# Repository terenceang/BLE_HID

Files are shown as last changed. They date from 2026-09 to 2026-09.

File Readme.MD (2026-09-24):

# SNES_BLE_HID - SNES controller to Bluetooth adapter (DA14585)

Plug an original SNES controller into this adapter and it becomes a wireless **Bluetooth LE
gamepad** - a standard HID-over-GATT device (HOGPD) that pairs with Windows, Android, iOS and
Linux with no drivers. The controller itself is untouched.

The adapter is built almost entirely from reused parts: the Bluetooth board is salvaged from an
e-paper **electronic shelf label (ESL)** (Renesas DA14585 + SPI flash; the same board as the
HMCLOCK project), powered by a reclaimed Li-ion cell with a TP4056-style USB charger and a
DC-DC converter, in a 3D-printed case. Repository: https://github.com/terenceang/SNES_BLE_HID

Firmware features: 12-button gamepad, battery level, deep sleep after 3 idle minutes (B wakes
it), and **signed over-the-air updates** - plus a PC updater and a browser tester (`tools/`).

## Hardware

| Prototype | In the case |
|---|---|
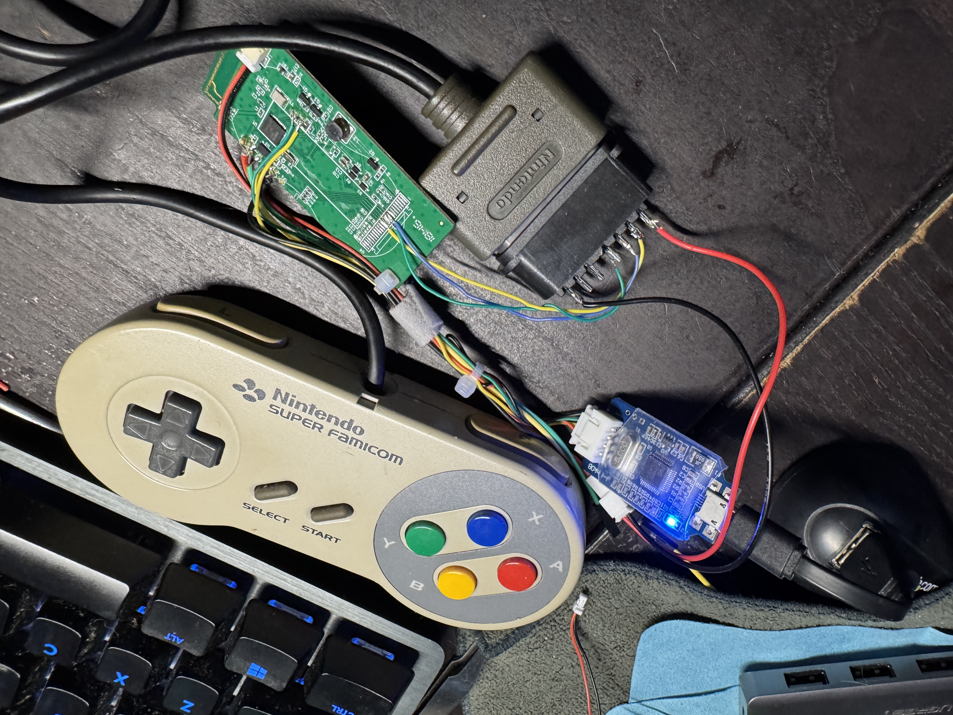
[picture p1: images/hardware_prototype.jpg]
Prototype: ESL board wired to a SNES socket, charger module and a Super Famicom pad
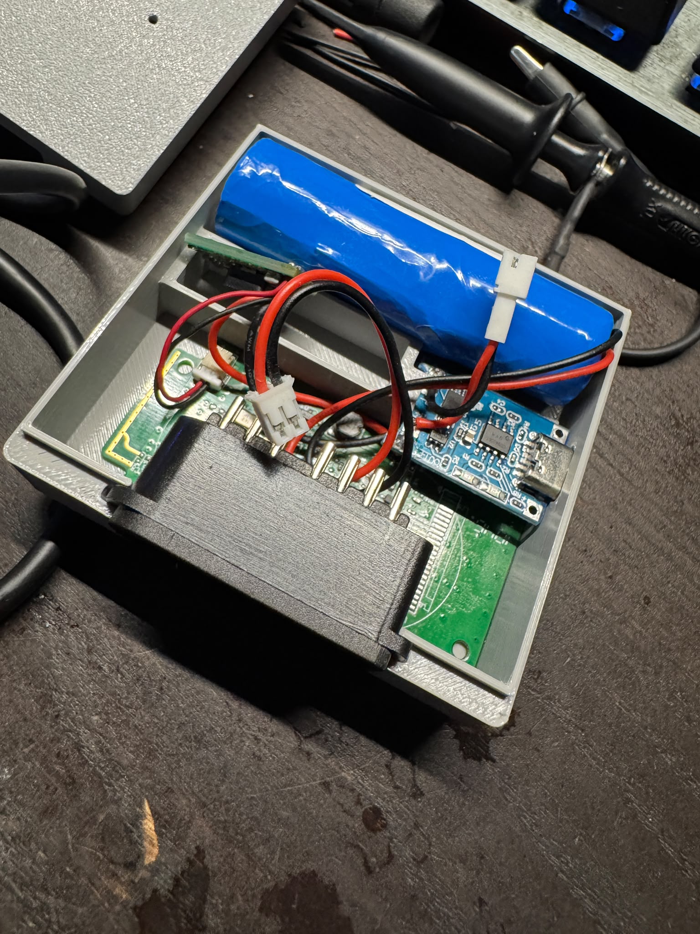
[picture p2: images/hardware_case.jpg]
Assembled: 18650 cell, USB-C charger/DC-DC module and the SNES socket on the ESL board in a 3D-printed case
|  |  |

- **Bluetooth board**: ESL board (DA14585, SPI flash, 32 kHz crystal). Its GPIOs were traced
  one by one; only three pads are needed - see [GPIO map](#gpio-map-da14585-qfn40).
- **SNES socket** wired to pads E09 (LATCH), E10 (DATA), E12 (CLOCK) plus supply and GND
  (see [Running](#running) for the pinout).
- **Power**: Li-ion cell (18650 in the case) -> USB charger module (TP4056-style, USB-C) ->
  DC-DC converter -> the board. The firmware's battery % reads the chip's supply after the
  converter, scaled 2.2 V = 0 % .. 2.8 V = 100 % (see [Battery level](#battery-level)).
- **Case**: 3D printed - see [3D-printed case](#3d-printed-case).
- **Programming**: J-Link on the test points (SWD) for the first install; after that, updates
  go over the air - see [Programming](#programming-swd).

### 3D-printed case

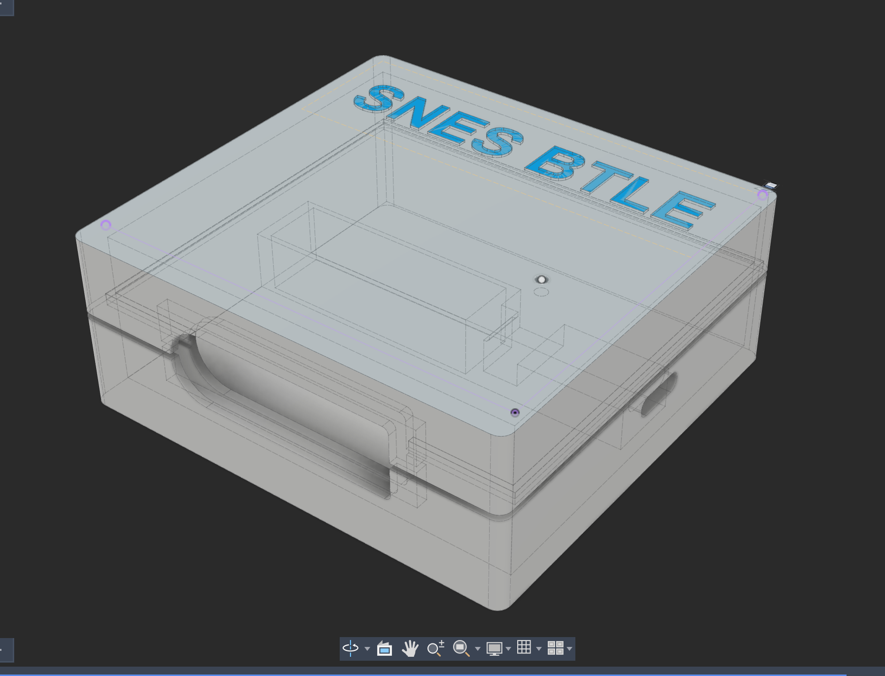
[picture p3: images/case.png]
Case model: base with SNES socket opening and USB slot, lid embossed "SNES BTLE"


CAD model: [`3D/SNES BLE.step`](3D/SNES%20BLE.step) (STEP AP214, exported from Autodesk
Fusion; opens in any CAD tool - export the bodies to STL/3MF for your slicer).

- Two parts: a **base** that holds the ESL board, the charger/DC-DC module and the cell (see
  the photo above), and a **lid** with "SNES BTLE" embossed on top.
- Front opening for the **SNES controller socket**; side slot for the **USB-C** charging port.
- Check the cell and socket fit against your own parts before printing - 18650 cells and SNES
  sockets vary slightly.

### Programming (SWD)

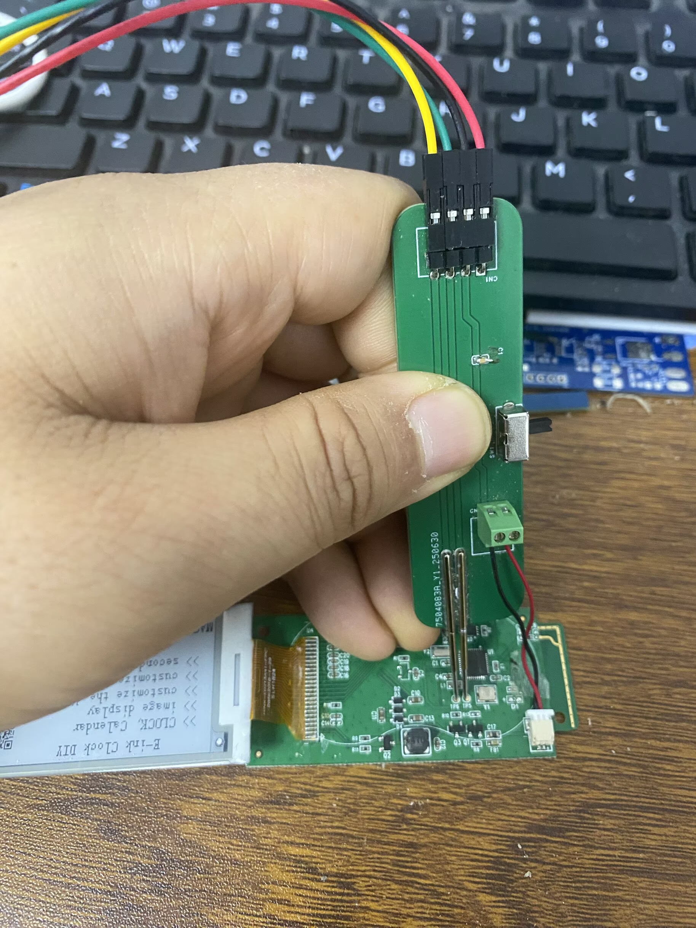
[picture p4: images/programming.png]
Pogo-pin jig on the board's SWD test points, J-Link wires attached


The first firmware goes in over SWD: a pogo-pin jig on the test points (TP5 SWCLK, TP6 SWDIO,
plus power/GND - see [Test points](#test-points-tp)) and a J-Link, then `bash Keil_5/flash.sh`
(see [Build and flash](#build-and-flash)). The image installs itself into SPI flash; after
that, updates go over the air ([OTA](#updating-over-the-air-ota)).

## Overview

- **Profile**: HID Service (UUID 0x1812) via the SDK `hogpd` profile (device role)
  - Report Map: USB HID Game Pad, Report ID 1, 12 buttons (`hid_report_map`, 31 bytes)
  - 1 input report (2 bytes: 16-bit little-endian button bitmap, bits [11:0] used), notifiable
  - HID Information (bcdHID 1.01, normally connectable, remote wake)
  - Protocol Mode characteristic, Report protocol only (no boot reports; a host request
    for Boot protocol is refused, since HOGPD would then reject every input report)
- **Device Information Service** (0x180A, SDK `diss` + `app_diss`): manufacturer
  `motionfxdesign`, model `BT-SNES`, firmware revision = `APP_VERSION`, PnP ID (VID 0xFFFF /
  PID 0x0001 - unassigned placeholder, version = `APP_VERSION_BCD`, e.g. `REV&0055` for 0.5.5
  in Device Manager > the pad's HID device > Details > Hardware Ids). BLE tools (nRF Connect)
  show the Firmware Revision string. Windows caches the PnP ID at pairing, so its REV stays at
  the paired version after an update - the web tester's helper reads the live version instead.
- **Buttons** (`SNES_BUTTON_*` in `src/user_hid_hogpd.h`), bit 0 to 11:
  A, B, Select, Start, D-pad Up, Down, Left, Right, X, Y, L, R
- **GAP**: peripheral, general discoverable; advertising data carries the HID
  service UUID, gamepad appearance (0x03C4), and the device name. The name is built
  at runtime as `BT-SNES-XXXXXX`, where `XXXXXX` is the last 3 octets of the chip's
  own BD address (`dev_bdaddr`) so multiple pads are distinguishable
  (`user_app_adv_set_name()` in `src/user_hid.c`; `USER_DEVICE_NAME` in
  `user_config.h` is deliberately left empty).
- **Security**: pairing and bonding are mandatory for HID hosts.
  Just Works (`GAP_IO_CAP_NO_INPUT_NO_OUTPUT` + `GAP_AUTH_BOND | GAP_AUTH_SEC`),
  unauthenticated pairing with encryption (`GAP_SEC1_NOAUTH_PAIR_ENC`), security
  requested on connect (`DEF_SEC_REQ_ON_CONNECT`). Bond data is stored by the SDK
  default bond database.

The SDK provides the HOGPD profile task but no application module for it, so the
application supplies the glue in `src/user_hid_hogpd.c`:

- `app_hogpd_create_db()` - sends `GAPM_PROFILE_TASK_ADD_CMD` with a
  `struct hogpd_db_cfg` payload (registered in `user_prf_funcs[]`,
  see `src/config/user_callback_config.h`)
- `app_hogpd_enable()` - sends `HOGPD_ENABLE_REQ` on each connection
- message handlers for `HOGPD_NTF_CFG_IND`, `HOGPD_REPORT_REQ_IND`,
  `HOGPD_PROTO_MODE_REQ_IND`, `HOGPD_CTNL_PT_IND`, `HOGPD_REPORT_UPD_RSP`,
  dispatched from `user_catch_rest_hndl()` in `src/user_hid.c`. `HOGPD_CTNL_PT_IND`
  (HID Control Point Suspend/Exit-Suspend) pauses/resumes the SNES poll timer; the suspend
  is remembered until Exit-Suspend or the next connection.

## Project layout

```
Keil_5/
├── BLE_HID.uvprojx             Keil project, 1 target: DA14585
└── flash.sh                    J-Link RAM load (+ marker so the image installs itself)
src/
├── user_hid.c/.h               GAP flow, idle/deep sleep, OTA mode, message dispatch
├── user_hid_hogpd.c/.h         HOGPD glue, Report Map, SNES pad driver, battery, CCC persistence
├── ota_verify.c/.h             OTA image signature check (SHA-256 + ROM ECDSA P-256)
├── selflash.c/.h               installs a J-Link-loaded image into SPI flash
├── config/                     SDK config headers; app_version.h = the firmware version,
│                               ota_pubkey.h = OTA signing public key
└── platform/                   pad/peripheral initialization
tools/
├── suota.py                    OTA updater (window/CLI), --sign/--keygen, --serve helper
├── suota_protocol.json         protocol constants shared by suota.py and web/
├── build_exe.bat               builds tools/dist/suota.exe (standalone)
└── web/                        browser tester: controller test, version, battery, OTA (React)
3D/                             SNES BLE.step - 3D-printed case (STEP)
docs/                           Programming.md (build/flash/flash map), pinout sheets
images/                         photos and diagrams used here
```

## Build and flash

See `docs/Programming.md` for the full procedure. Short version:

Build in Keil (`Keil_5/BLE_HID.uvprojx`) or from the command line (the project must sit in the
SDK tree at `projects/target_apps/ble_examples/BLE_HID` - it includes the SDK by relative path):

```
UV4 -b Keil_5/BLE_HID.uvprojx -t DA14585 -j0 -o build_log.txt
bash Keil_5/flash.sh   # J-Link RAM load; the firmware then installs itself into SPI flash
```

The project currently has only the `DA14585` target (DA14586/531/531-01/535 were removed;
the source still has `#if` branches for them). Build output is gitignored.

## Running

1. Run `bash Keil_5/flash.sh` once, then power-cycle the board. UART2 log on P0.4, 115200,
   but `CFG_PRINTF` is off by default (production build) - re-enable it in
   `src/config/da14585_config_basic.h` and reflash if you need the log.
2. On the host, scan and pair with **`BT-SNES-XXXXXX`** (`XXXXXX` = the pad's own MAC
   suffix; Just Works - confirm the pairing prompt when asked).
3. Once the host enables input report notifications, the firmware polls the SNES
   controller every 10 ms (LATCH P2_0, CLOCK P2_1, DATA P0_7) and sends a report when a
   button changes (visible in the host's game controller tester). Polling stops on
   disconnect, and also pauses/resumes if the host sends HID Control Point Suspend/Exit-Suspend.
   Wiring, SNES controller plug (7-pin, viewed face-on, pins toward you) to chip:

   ```
    ___________________________
   /                            \
   |  1   2   3   4    5  6  7  |
   \____________________________/
   ```
   1=+5V  2=CLK  3=Latch  4=D0  5=D1  6=SEL(IO)  7=GND

   SNES connector pinout

   | SNES pin | Signal | Chip pin | Wire |
   |---|---|---|---|
   | 1 | +5V | 3.3 V (pad runs fine off 3.3 V) | |
   | 2 | CLK (data clock) | P2_1 (CLOCK), PCB pad E12 (traced) | yellow |
   | 3 | Latch | P2_0 (LATCH), PCB pad E09 (traced) | blue |
   | 4 | D0 (serial data, standard controller) | P0_7 (DATA), PCB pad E10 (traced) - internal pull-up, so a missing pad reads as no buttons | green |
   | 5 | D1 (2nd data line, multitap) | not wired - single controller only | |
   | 6 | SEL / IO (bidirectional, multitap/light pen) | not wired | |
   | 7 | GND | GND | |
4. If a report notification fails (`HOGPD_REPORT_UPD_RSP` error), the next poll resends the
   pad state, so a lost release can't leave a button stuck on the host.
5. **Idle power-off**: after 3 minutes of advertising with no connection (`ADV_IDLE_TIMEOUT` in
   `src/user_hid.c`) the chip goes into deep sleep (RAM off, radio off). **Press B** to wake it -
   waking reboots the chip, which boots from flash and advertises again, so a bonded host
   reconnects on its own. It works by holding LATCH high during sleep: the pad then loads its
   shift register continuously and DATA follows B live, and B pulls DATA low, triggering the GPIO
   wake-up controller. Other buttons don't wake it. With no pad plugged in, only a power cycle
   wakes it.
6. **Idle while connected**: 3 minutes with no button change (`CONN_IDLE_TIMEOUT` in
   `src/user_hid.c`, restarted by `user_hid_activity()` on every change) disconnects and goes
   straight into the same deep sleep. Press B to wake it and reconnect.

## Web tester (`tools/web`)

A page for testing the pad in Chrome or Edge:

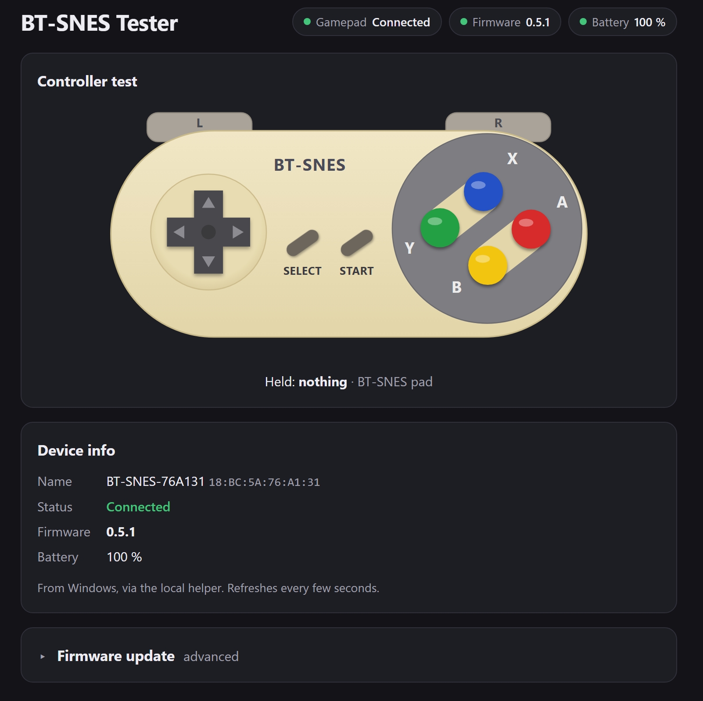
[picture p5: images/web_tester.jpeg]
BT-SNES Tester: controller test, status chips and device info


*Paired pad connected: the status chips and Device info (firmware 0.5.1, battery 100 %) come
from Windows through the helper; pressed buttons sink and get a ring on the drawing.*

- **Controller**: SNES layout that lights up as you press buttons (browser Gamepad API - the
  pad must be connected to Windows; press a button once so the browser reports it).
- **Device**: firmware version, battery and **OTA mode**. With the helper running they fill in
  by themselves for the pad paired with Windows: battery from Windows' device properties, and -
  once per connection, over the Windows link - the live Firmware Revision and whether the pad is
  in OTA mode (its update service only answers in OTA mode). Without the helper, a Web Bluetooth
  button reads version and battery directly.
- **Firmware update (OTA)**: same protocol and signed-image check as `tools/suota.py`; through
  the helper it uses the Windows connection, so the pad doesn't need to be removed first.
  **Install** stays disabled, with the reason, until the pad is connected and in OTA mode.

```
python tools/suota.py --serve   # helper on 127.0.0.1:8765 (or: suota.exe --serve)
cd tools/web
npm install        # once
npm run dev        # opens http://localhost:5173
npm test           # checks the image builder (matches tools/suota.py byte for byte)
```

The helper only listens on 127.0.0.1 and only answers pages served from localhost; an update
also needs a signed file. Without the helper, Device/OTA use Web Bluetooth, which only works on
`http://localhost` or HTTPS and only sees pads that are advertising (a pad connected to Windows
isn't - remove it in Windows Bluetooth settings first). `npm run build` writes a static copy to
`tools/web/dist/`.

## Updating over the air (OTA)

The pad takes firmware updates over Bluetooth with the Renesas SUOTA protocol, from the
PC tool in `tools/`. A J-Link is only needed once, to install v0.5.0 or later. Only
**signed** firmware is accepted (see below), so the Renesas phone app can't be used.

0. **Sign the build** (developer PC with the private key):
   `python tools/suota.py --sign Keil_5/out_DA14585/Objects/BLE_HID_585.bin` writes
   `BLE_HID_585_signed.bin`. That file is what you distribute and send.
1. **Enter OTA mode** - any of:
   - while it's running: **hold L + R + Start + Select for 3 s** - it reboots into OTA mode
     (v0.5.4+; needs the pad connected, since that's when it's polled);
   - while it's asleep: **hold Start + Select and tap B** - B wakes (reboots) it with the combo held;
   - power it on while holding **Start + Select**.

   Only then is the update service unlocked (otherwise it refuses every request), and the idle
   timeouts stretch to 10 minutes (enough for an update); after that it deep-sleeps, which also
   ends OTA mode.
2. Send it: the web tester (Firmware update -> Install update), or `tools\dist\suota.exe` /
   `python tools/suota.py` (pick the `_signed.bin` and the pad, press **Update**), or on the
   command line `python tools/suota.py FILE_signed.bin [-d ADDRESS]`. The tools refuse unsigned
   files and pair if needed (the service requires an encrypted link). The pad checks the CRC,
   then the signature (about 2 s), and reboots into the new firmware - in normal mode.

**Signing.** A signed file is the firmware + `BTSNSIG1` + an ECDSA P-256 signature of its
SHA-256. After the transfer the pad hashes the image in flash and verifies the signature
against the public key compiled into it (`src/config/ota_pubkey.h`), using the micro-ecc
code in the DA14585 ROM. If it doesn't verify - unsigned, corrupted, or signed with
another key - the pad clears the slot's valid flag and reports "signature check failed";
the old firmware keeps booting. The private key is `tools/keys/ota_private.pem`: **not in
git, back it up**. Lose it and new firmware can only go in over J-Link (then rebuild with a
new key from `python tools/suota.py --keygen`, which refuses to overwrite an existing one).
Signatures stop foreign and accidental images, not downgrades: an older signed image is
still accepted. J-Link (`flash.sh`) bypasses all of this - physical access wins.

How it's safe: the image goes into the **other** flash slot (from the product header at
`0x38000`; this unit: `0x04000` and `0x1F000`), is marked valid only after its CRC checks
out, and the boot ROM boots the newest valid slot - an interrupted update leaves the old
firmware booting. Both slots stay clear of the bond/CCC sectors (`0x1D000-0x1EFFF`) for any
image that fits in RAM. (SUOTA refuses an image whose version *and* timestamp match a slot;
the tools stamp every send, so re-sending the same build is accepted.)

Notes:
- After first installing v0.4.0, **remove and re-pair the pad** in Windows: it added
  services (Device Information, SUOTA) and Windows caches the old list.
- Building `suota.exe`: run `tools\build_exe.bat` (Python 3 on PATH; it makes its own venv
  with `bleak` + PyInstaller). The exe is unsigned, so SmartScreen asks once (*More info ->
  Run anyway*). `python tools/suota.py --selftest` checks the image builder.
- Security: OTA mode + encrypted link stops drive-by connections; the signature makes sure
  only firmware signed with your key is installed.
- `suota.exe` only sends files; signing and key generation need Python with `cryptography`
  (`pip install cryptography`).

## GPIO map (DA14585, QFN40)

The chip has 23 GPIOs (source: the HMCLOCK PCB pinout in `../HMCLOCK/Hardware/pinout_0.pdf`, same PCB).
P1_4 and P1_5 are the SWD pins (SWCLK/SWDIO, test points TP5/TP6) - leave them to the debugger;
P3_1 to P3_7 do not exist on this package.

### Usable pins (reachable on the PCB, traced)

Only these GPIOs reach a solderable point; every other GPIO is NC or taken by the SPI flash.

| GPIO | PCB point | Used for here | Notes |
|---|---|---|---|
| P2_0 | pad E09 | SNES LATCH | blue wire |
| P0_7 | pad E10 | SNES DATA | green wire; internal pull-up; deep-sleep wake pin (B) |
| P2_1 | pad E12 | SNES CLOCK | yellow wire |
| P0_4 | TP7 | UART2 TX (debug log) | free if `CFG_PRINTF` stays off |
| P0_5 | TP8 | UART2 RX | shared with SPI flash DI - avoid driving it |
| P2_5 | R4 / D1 pads | free | unpopulated green-LED footprint - solder to the pad that shows P2_5; easiest spare pin |
| P2_3 | Q3 pad | free | drives Q3 (HMCLOCK PWR_EN); remove Q3 (and any gate pull resistor) to reuse |

Also on test points: TP1 VCC, TP2 GND, TP3 VPP, TP4 RST, TP5 SWCLK, TP6 SWDIO (keep for J-Link).

### All GPIOs

| Pin | Status | Function here | Same PCB in HMCLOCK |
|---|---|---|---|
| P0_0 | **used** | SPI flash CLK |  |
| P0_1 | NC | not connected here (traced: not found) | e-paper SCLK (U5.13) |
| P0_2 | NC | not connected here (traced: not found) | red LED |
| P0_3 | **used** | SPI flash EN (CS) |  |
| P0_4 | **used** | UART2 TX, PCB TP7 (traced; debug, 115200 8N1) |  |
| P0_5 | **used** | UART2 RX, PCB TP8 (traced; not driven by firmware); also SPI flash DI |  |
| P0_6 | **used** | SPI flash DO |  |
| P0_7 | **used** | SNES DATA, PCB pad E10 (traced) | e-paper D/C |
| P1_0 | NC | not connected here (traced: not found) | e-paper RST |
| P1_1 | NC | not connected here (traced: not found) | e-paper BUSY |
| P1_2 | NC | not connected here (traced: not found) |  |
| P1_3 | NC | not connected here (traced: not found) |  |
| P2_0 | **used** | SNES LATCH, PCB pad E09 (traced) | e-paper SDI |
| P2_1 | **used** | SNES CLOCK, PCB pad E12 (traced) | e-paper CS |
| P2_2 | NC | not connected here (traced: not on E01) | e-paper HLT_CTL |
| P2_3 | free | goes to transistor Q3 (traced) | PWR_EN |
| P2_4 | NC | not connected here (traced: not found) | U4 |
| P2_5 | free | only to green LED D1 via R4 (both unpopulated, traced) - solderable spare | green LED |
| P2_6 | NC | not connected here (traced: not found) |  |
| P2_7 | NC | not connected here (traced: not found) |  |
| P2_8 | NC | not connected here (traced: not found) |  |
| P2_9 | NC | not connected here (traced: no blue LED found) | blue LED |
| P3_0 | NC | not connected here (traced: not found) |  |

### Test points (TP)

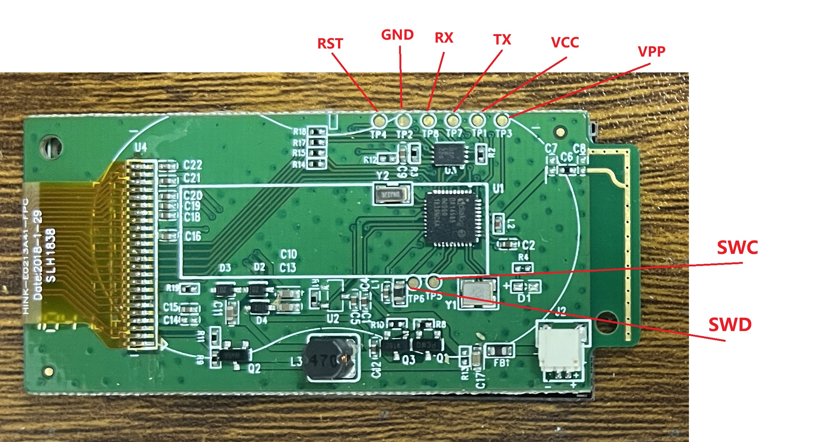
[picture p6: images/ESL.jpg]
Test points


| TP | Signal | Chip pin | Use here |
|---|---|---|---|
| TP1 | VCC |  | supply |
| TP2 | GND |  | ground |
| TP3 | VPP |  | OTP programming voltage |
| TP4 | RST | RST | reset (J-Link) |
| TP5 | SWC | SWCLK | J-Link SWD clock |
| TP6 | SWD | SWDIO | J-Link SWD data |
| TP7 | TX | P0_4 (traced) | UART2 TX (debug log, 115200 8N1) |
| TP8 | RX | P0_5 (traced) | UART2 RX (not driven by firmware; shared with SPI flash DI) |

### E-paper connector (PCB pads E01-E24)

Pad numbers do **not** follow the HMCLOCK FPC pin order in `docs/pinout_0.md` (E09 carries the sheet's
SDI net, E10 its D/C net), so only traced entries are reliable. Sheet signal = FPC pin `xx` on the sheet (unreliable, see above); HMCLOCK net = what the sheet calls the traced GPIO.
Trace one pin at a time to confirm - with several pulsing, idle pads pick up neighbours.

| Pad | Sheet signal (FPC pin xx) | GPIO | HMCLOCK net | Function here | Status |
|---|---|---|---|---|---|
| E01 | HLT_CTL | ? |  |  | not P2_2 (traced) |
| E02 | GDR | ? |  |  | not traced |
| E03 | RESE | ? |  |  | not traced |
| E04 | VGL | ? |  |  | not traced |
| E05 | VGH | ? |  |  | not traced |
| E06 | TSCL | ? |  |  | not traced |
| E07 | TSDA | ? |  |  | not traced |
| E08 | BS | ? |  |  | not traced |
| E09 | nBUSY | P2_0 | e-paper SDI | **SNES LATCH** (blue wire) | traced |
| E10 | nRST | P0_7 | e-paper D/C | **SNES DATA** (green wire) | traced |
| E11 | D/C | ? |  |  | not P0_1 (traced) |
| E12 | nCS | P2_1 | e-paper nCS | **SNES CLOCK** (yellow wire) | traced |
| E13 | SCLK | ? |  |  | 314 Hz seen in a 7-pin P0 test - likely crosstalk |
| E14 | SDI | ? |  |  | not traced |
| E15 | VDDIO | ? |  |  | not traced |
| E16 | VCI | ? |  |  | not traced |
| E17 | VSS | ? |  |  | not traced |
| E18 | VDDIO | ? |  |  | not traced |
| E19 | VPP | ? |  |  | not traced |
| E20 | VSH | ? |  |  | not traced |
| E21 | PREVGH | ? |  |  | not traced |
| E22 | VSL | ? |  |  | not traced |
| E23 | PREVGL | ? |  |  | not traced |
| E24 | VCOM | ? |  |  | not traced |

Traced NC (not found on any pad): P0_1, P0_2, P1_0-P1_3, P2_2, P2_4, P2_6-P2_9, P3_0.

RX on TP8 verified by pulsing P0_5. The board has no populated LED here (green: D1 + R4 footprints on P2_5, unpopulated; red P0_2 and blue P2_9 traced, not found).
P0_1/P0_2: not routed to any pad (traced) and unused by the firmware - never reserved or configured, so they stay
at the reset default (input, pull-down). The battery reading uses the internal VBAT channel, not these ADC pins.
SNES pins: LATCH P2_0, CLOCK P2_1, DATA P0_7. Battery: VBAT3V/VBAT1V are module supply pins; see the Battery section.
The defines live in `src/config/user_periph_setup.h` (reserved in `GPIO_reservations()`,
configured in `set_pad_functions()` in `src/platform/user_periph_setup.c`); update this map when you add pins.

## Battery level

Standard Battery Service (0x180F) next to the HID service. The level comes from the chip's
VBAT via the on-chip ADC (`adc_get_vbat_sample()`, offset-calibrated before every sample -
the calibration registers are lost while the chip sleeps), converted with the same table as HMCLOCK (`batt_cal()` in
`src/user_hid_hogpd.c`), stretched onto the adapter's supply range: 2.2 V = 0%, 2.43 V = 4%,
2.67 V = 28%, >=2.8 V = 100% (`BATT_EMPTY_MV` / `BATT_FULL_MV`). It is polled every 60 s
while the host has battery notifications enabled (`batt_timer_update()` gates the timer on
the battery CCC, same pattern as the HOGPD poll gate) and notified on change. The level is
also pushed on every connection (`user_batt_enable()`) and when the host enables notifications
(`user_batt_ntf_cfg_ind_handler()`): the SDK Battery Service only stores a level when it is
sent a `BASS_BATT_LEVEL_UPD_REQ`, so without the push a host read returns 0% until the level
changes. The battery CCC is saved to flash with the HID one and restored on reconnect, since
bonded hosts don't rewrite it. It measures the chip's supply after the DC-DC converter, not the cell:
it only tracks the battery if the converter's output sags with the cell; a converter that holds
its output steady reads 100% until it drops out. `user_batt_mv` holds the
last reading in mV (read it with a debugger, e.g. 3332 mV on the bench). For a true LiPo
percentage, wire a divider from LiPo+ to an ADC pin (P0_0-P0_3) and read that - but P0_1/P0_2 are not routed on
this PCB (traced) and P0_0/P0_3 are the SPI flash, so it needs a bodge wire to the chip.
The SDK `app_bass` module is CR2032-only and unused; its build stubs are in
`user_profiles_config.h`, and `bass.c`/`bass_task.c` are in the Keil project.

## Persistence (DA14585, SPI flash)

Bonds and the host's notification setting survive power cycles, so a bonded
Windows/Android host reconnects without re-pairing:

- `CFG_SPI_FLASH_ENABLE` is defined in `src/config/da14585_config_basic.h`, which
  makes the SDK bond DB use SPI flash at `0x1E000` (1 sector). Pins (DA14585):
  EN=P0_3, CLK=P0_0, DO=P0_6, DI=P0_5; the DA14586 uses its internal flash.
- The HID and Battery notification (CCC) values are stored in the sector at `0x1D000`
  (`ccc_flash_save/load` in `src/user_hid_hogpd.c`), restored in `app_hogpd_enable()` and
  `user_batt_enable()`. Records from v0.1.0 (HID CCC only) still load; battery starts off.
  Single host only; a different host inherits it until it writes its own.
- Keep firmware images out of `0x1D000-0x1EFFF`. To wipe bonds, erase those sectors.
- The SDK does not load the bond DB by itself: `user_app_init()` must call
  `app_easy_security_bdb_init()` (`default_app_on_init()` does not). Without it the pad
  forgets every bond on reboot.
- Firmware persistence: after a J-Link RAM load (`flash.sh`), `selflash_run()` installs the
  image into the boot slot from the product header; see `docs/Programming.md`. OTA updates
  write the other slot themselves (see "Updating over the air").
- Removed targets (DA14531/35) would keep RAM-only bonds and no self-flash
  (`CFG_SPI_FLASH_ENABLE` undefined there).

## Customizing

- **Send your own input**: call `app_hogpd_send_gamepad_report(conidx, buttons)`
  with an OR of `SNES_BUTTON_*`, or `app_hogpd_send_input_report(conidx, report, length)`
  for raw reports. Reports are only delivered while the host keeps notifications
  enabled. The pad driver is `snes_read()` / `poll_timer_cb()` in `src/user_hid_hogpd.c`.
- **Change the button count**: `SNES_BUTTON_COUNT` (`user_hid_hogpd.h`) is the single source -
  the Report Map's count and padding, `HID_REPORT_LEN` and the report mask follow from it; add
  the new entries to `snes_map[]` (a compile-time check enforces the count; 1-16 buttons, not a
  multiple of 8).
- **Change HID topology** (add reports, axes, other collections): edit the Report Map
  (`hid_report_map`; its length is `sizeof(hid_report_map)`), the `APP_HOGPD_*` defines in
  `src/config/user_profiles_config.h`, and the appearance in `src/config/user_config.h`;
  keep report IDs in sync. Hosts cache the Report Map, so delete the old bond on the
  host after changing it.
- **Security**: to require MITM protection instead of Just Works, switch
  `USER_CFG_FEAT_IO_CAP` (e.g. `GAP_IO_CAP_DISPLAY_YES_NO`) and add `GAP_AUTH_MITM`
  plus `GAP_SEC1_AUTH_PAIR_ENC` in `src/config/user_config.h`.

## Troubleshooting

UART2 log (P0.4, 115200) prints `SEC:` lines for pairing/encryption and the host address
(`peer ..`) on each connection - but `CFG_PRINTF` is off by default (see Running above), so
re-enable it and reflash before using any of this table.

| Symptom | Cause / fix |
|---|---|
| Connects then drops, `user_app_disconnect! reason=13`, log shows `SEC: encrypt_req_ind` | Host holds a bond the pad does not have (pad bond DB empty/wiped). Remove the pad on the host (also toggle Bluetooth, and check other paired devices), pair again. |
| `encrypt_req_ind` then disconnect (no `encrypt_ind`) after every reboot, even right after pairing | Bond DB not loaded from flash: missing `app_easy_security_bdb_init()` in `user_app_init()`. |
| `reason=08` shortly after notifications enabled | Link supervision timeout; seen once, cause unconfirmed (suspect SPI-flash erase in `ccc_flash_save()` / bond write blocking the radio). Re-check on a fresh pair. |
| Good log: `encrypt_req_ind`, `encrypt_ind auth=01`, `GATTC_MTU_CHANGED_IND` | Bonded reconnect works. |
| Web tester: Install disabled, "isn't in OTA mode" | Hold L + R + Start + Select for 3 s (it reboots and reconnects; the page re-checks). On firmware older than 0.5.4: let it sleep, then hold Start + Select and tap B. |
| OTA: "Device ... was not found" | Old helper/tool that scanned for the pad; a pad connected to Windows doesn't advertise. Current `suota.py` opens it through Windows' paired-device lookup - update the tool. |
| Windows / Device Manager still shows the old version after an update | Windows keeps the PnP ID from pairing. The web tester (helper) shows the live version; re-pair to refresh Windows. |
| `flash.sh` load doesn't survive a power cycle | Check `flash.sh` printed `w4 <addr>, 0x5E1FF1A5` (the install marker) - it needs the `.map` from the same build. Firmware older than 0.5.2 also mis-ordered image ids next to an OTA image (fixed in `selflash.c`). |
| Host shows 0% battery, mainly after a reconnect | Fixed in v0.2.0: the level is pushed to the Battery Service on every connection and the battery CCC is restored for bonded hosts. If it persists, check the UART `battery: X mV, Y%` line to confirm the ADC reading itself is sane. |

After re-flashing with a bond-layout change, remove the bond on the host and re-pair.

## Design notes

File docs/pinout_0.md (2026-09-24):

# DA14585 module pinout (QFN40)

## Module pins

| Pin | Name | Board net | E-paper | BLE_HID (SNES) |
|---|---|---|---|---|
| 1 | P00 | SPI.CLK |  | SPI flash CLK |
| 2 | P01 | U5.13 | SCLK | NC (traced) |
| 3 | P02 | LED_Red |  | NC (traced) |
| 4 | P03 | SPI.CS |  | SPI flash CS |
| 5 | P30 | - |  | NC (traced) |
| 6 | P04 | UART_TX |  | UART2 TX (TP7, traced) |
| 7 | P05 | SPI.SO | UART_RX | UART2 RX (TP8, traced) / SPI flash DI |
| 8 | P21 | U5.12 | CS | SNES CLOCK (pad E12, traced) |
| 9 | P06 | SPI.SI |  | SPI flash DO |
| 10 | P07 | U5.11 | DC | SNES DATA (pad E10, traced) |
| 11 | 32Kp |  |  |  |
| 12 | 32Km |  |  |  |
| 13 | P22 | U5.1 | HLT_CTL | NC (traced) |
| 14 | VBAT_RF |  |  |  |
| 15 | VBAT3V |  |  |  |
| 16 | GND |  |  |  |
| 17 | RST |  |  |  |
| 18 | P23 | PWR_EN |  | free - drives Q3 (traced) |
| 19 | VDCDC |  |  |  |
| 20 | P24 | 接U4 (to U4) |  | NC (traced) |
| 21 | SWITCH |  |  |  |
| 22 | P10 | U5.10 | RST | NC (traced) |
| 23 | VBAT1V |  |  |  |
| 24 | P11 | U5.9 | BUSY | NC (traced) |
| 25 | SWDIO |  |  |  |
| 26 | SWCLK |  |  |  |
| 27 | P12 | - |  | NC (traced) |
| 28 | P13 | - |  | NC (traced) |
| 29 | 16Mp |  |  |  |
| 30 | 16Mm |  |  |  |
| 31 | VDCDC_RF |  |  |  |
| 32 | P25 | LED_Green |  | free - unpopulated D1/R4 (traced) |
| 33 | P26 | - |  | NC (traced) |
| 34 | RFIOm |  |  |  |
| 35 | RFIOp |  |  |  |
| 36 | P27 | - |  | NC (traced) |
| 37 | P28 | - |  | NC (traced) |
| 38 | VDD |  |  |  |
| 39 | P29 | LED_Blue |  | NC (traced) |
| 40 | P20 | U5.14 | SDI | SNES LATCH (pad E09, traced) |

## E-paper connector

FPC pin numbers as on the HMCLOCK sheet. The BLE_HID PCB pads `Exx` do not follow this order - see `Readme.MD` for the traced pads.

| GPIO | FPC pin | Signal | Note |
|---|---|---|---|
| P22 | 1 | HLT_CTL |  |
|  | 2 | GDR |  |
|  | 3 | RESE |  |
|  | 4 | VGL |  |
|  | 5 | VGH |  |
|  | 6 | TSCL | 温控IIC接口 (temperature sensor I2C, pins 6-7) |
|  | 7 | TSDA |  |
|  | 8 | BS | 1:3线  0:4线 (1 = 3-wire SPI, 0 = 4-wire) |
| P11 | 9 | nBUSY |  |
| P10 | 10 | nRST |  |
| P07 | 11 | D/C |  |
| P21 | 12 | nCS |  |
| P01 | 13 | SCLK |  |
| P20 | 14 | SDI |  |
|  | 15 | VDDIO |  |
|  | 16 | VCI |  |
|  | 17 | VSS |  |
|  | 18 | VDDIO |  |
|  | 19 | VPP |  |
|  | 20 | VSH |  |
|  | 21 | PREVGH |  |
|  | 22 | VSL |  |
|  | 23 | PREVGL |  |
|  | 24 | VCOM |  |

在Flash的0x39000处，保存有GPIO的配置信息 (GPIO configuration is stored in flash at 0x39000.)

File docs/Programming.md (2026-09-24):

# Build, flash and persist the BLE_HID firmware (DA14585 + SPI flash)

## 1. Compile

Keil MDK 5 with Arm Compiler 6 (here installed per-user at
`C:\Users\<you>\AppData\Local\Keil_v5`). Close the project in µVision first, or Keil
overwrites the `.uvprojx`.

```
cd Keil_5
"/c/Users/<you>/AppData/Local/Keil_v5/UV4/UV4.exe" -b BLE_HID.uvprojx -t DA14585 -j0 -o build_log.txt
```

Success = `0 Error(s), 0 Warning(s)` at the end of `build_log.txt`. Output:
`Keil_5/out_DA14585/Objects/BLE_HID_585.bin` (and `.hex`, `.axf`). Only the `DA14585`
target exists in the project.

(`UV4 -f` does nothing useful here: the DA14585 has no internal flash to program.)

## 2. Flash

The DA14585 runs from RAM at `0x07FC0000`; on every power-on its boot ROM copies an image
from external SPI flash into RAM. So "flashing" is: RAM-load the build once, let the firmware
copy itself into SPI flash (`selflash_run()`), then power-cycle.

```
bash Keil_5/flash.sh          # J-Link (V9.60 default; override with JLINK=...)
```

`flash.sh` freezes the watchdog, remaps SysRAM to address 0, loads the `.bin` at
`0x07FC0000`, sets SP/PC from the vector table and runs (same steps as the SDK's
`sdk/common_project_files/misc/sysram_case23.ini`). Alternatively start a µVision debug
session (debugger `LOAD` does the same RAM load).

Serial log: UART2 TX = P0.4, 115200 8N1 (`CFG_PRINTF`) - **off by default** in this project
(`src/config/da14585_config_basic.h`, disabled for production); re-enable and reflash to get
any of the log below. Close terminals before running the script if you need the J-Link, and
only one program can hold the COM port. Expected log (with `CFG_PRINTF` on):

```
BLE_HID vX.Y.Z user_app_init! ...
selflash: installing 28472 bytes at 4000     <- first run of a new build
selflash: done
```

and `selflash: up to date` on later boots. The first install takes a few seconds; don't cut
power during it. If it fails, just run `flash.sh` again (a RAM load never depends on flash).
With `CFG_PRINTF` off there's no log either way - the install still happens, just silently.

3. **Power-cycle** (debugger disconnected). The device should advertise as `BT-SNES-XXXXXX`
   (MAC-suffixed) with no debugger. Remove the device in Windows and re-pair once after
   flashing a build that changed bonding/flash layout, or the device name/appearance.

## How self-flash works (`src/selflash.c`)

The boot ROM reads the product header at flash `0x38000` (signature `70 52`, two image slot
addresses) and boots the newest valid slot: a 64-byte SUOTA header
(`70 51`, valid flag `AA`, image id, size, CRC32, version) followed by the body.
`selflash_run()` (called from `user_app_init()`):

0. runs only after a J-Link RAM load: `flash.sh` writes `0x5E1FF1A5` to `selflash_magic`
   (uninitialised retained RAM, address taken from the `.map`) before starting the image. A
   ROM boot from flash (power-on, OTA reboot, deep-sleep wake) leaves garbage there, so an
   image the ROM booted - including one installed over the air - is never rewritten. A RAM
   load from the µVision debugger doesn't set it, so it doesn't install; use `flash.sh`;
1. reads the product header; skips if missing/invalid;
2. CRC32s the running image (`0x07FC0000` .. start of ZI = exactly the `.bin` contents);
3. skips if slot 0 already has the same size/CRC/version **and** slot 0 is what the ROM boots
   (after an OTA update the other slot can hold a newer image id - then it reinstalls);
4. otherwise erases slot 0, writes the header (valid flag `FF`), the body, re-reads and
   verifies the CRC, and only then sets the valid flag `AA`, so an interrupted install is
   ignored. The image id is one above the newest valid slot, in the ROM/SUOTA order
   (higher is newer, 0 follows 0xFF, equal ids rank slot 1 newer - `app_find_old_img()`).

Safety: slot addresses come from the product header (they differ between units); install
is skipped if the slot is unaligned, beyond the flash size, or would overlap
`0x1D000-0x1EFFF` (bond DB + saved CCC) or `0x38000-0x3AFFF` (product header/pinouts).

## Flash map used by this project

| Address | Content |
|---:|---|
| `0x04000`+ (from product header) | firmware image slot 0 (selflash; OTA uses the older slot) |
| `0x1D000` | saved HID + battery notification (CCC) values |
| `0x1E000` | SDK bond database |
| `0x1F000`+ (from product header) | firmware image slot 1 (OTA) |
| `0x38000` | product header (never written by this code) |

## Limits

- The image is CRC'd from RAM after start-up; the few initialised-data bytes are already
  modified, but this is stable across boots so the up-to-date check holds.
- Overlapping slot layouts (e.g. `0x2000`/`0x4000`): installing into slot 0 overwrites slot 1.
- The product header must already exist on the flash; this code never creates it.
- Product header on this unit (read over J-Link): slots `0x04000` and `0x1F000`. Any image
  that fits the DA14585's 96 KB RAM ends below `0x1C000` / `0x37000`, clear of the
  bond/CCC sectors and the product header, so OTA needs no extra range check here. Re-check
  on a unit with a different product header.
- Verified on hardware: self-programming works (RAM load, `selflash: installing ... done`, boots from flash).

## Signed OTA images

`tools/suota.py --sign` appends `BTSNSIG1` + a 64-byte ECDSA P-256 signature (r || s,
big-endian) of SHA-256(firmware). The SUOTA header's code size covers the whole file, so
the boot ROM also copies the 72-byte trailer into RAM - right where zero-initialised data
starts, which the C startup clears, so it's harmless.

On the pad, `ota_check_new_image()` (`src/ota_verify.c`) runs from the SUOTA end callback
after the SDK has checked the CRC and set the valid flag: SHA-256 of the slot in flash, then
`uECC_verify()` from the ROM (the BLE stack's micro-ecc; checked on the chip with a
Python-made signature: big-endian inputs, 1.4 s, ~1.3 KB of stack - hence `STACK_SIZE=0x800`
in the project's assembler defines, up from the SDK's 0x600). The watchdog is frozen during
the verify. On failure it writes `0x00` over the valid flag (`0xAA`), which needs no erase.
The tool gets two statuses after "end": the SDK's CRC result, then the signature verdict
(`0x02` OK, `0x09` rejected).

Micro-ecc's own Thumb assembly doesn't build with Arm Compiler 6 LTO (`.syntax divided`),
and a second copy would clash with the ROM's symbols anyway - use the ROM's.

## Flashing gotchas

- Run `flash.sh` from Git Bash (from PowerShell, `bash` may resolve to WSL, which has no `/e/...`).
  Check the J-Link output shows `wreg MSP, <hex>` and `SetPC <hex>`; empty arguments mean the
  `.bin` was not read and the old flash image boots instead.
- `flash.sh` needs the UART (COM port) closed only for logging, not for flashing.
- To just reboot the pad without reflashing: J-Link `connect`, `r`, `g`. It boots from SPI flash.
- COM port here is a CH340 (COM36). Log capture needs no extra tools:
  PowerShell `System.IO.Ports.SerialPort` at 115200.

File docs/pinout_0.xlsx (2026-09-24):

 |  |  |  | BLE_HID (SNES)
1 | P00 | SPI.CLK |  | SPI flash CLK | P22 | 1 | HLT_CTL
2 | P01 | U5.13 | SCLK | NC (traced) |  | 2 | GDR
3 | P02 | LED_Red |  | NC (traced) |  | 3 | RESE
4 | P03 | SPI.CS |  | SPI flash CS |  | 4 | VGL
5 | P30 | - |  | NC (traced) |  | 5 | VGH
6 | P04 | UART_TX |  | UART2 TX (TP7, traced) |  | 6 | TSCL | 温控IIC接口
7 | P05 | SPI.SO | UART_RX | UART2 RX (TP8, traced) / SPI flash DI |  | 7 | TSDA
8 | P21 | U5.12 | CS | SNES CLOCK (pad E12, traced) |  | 8 | BS | 1:3线 0:4线
9 | P06 | SPI.SI |  | SPI flash DO | P11 | 9 | nBUSY
10 | P07 | U5.11 | DC | SNES DATA (pad E10, traced) | P10 | 10 | nRST
 |  |  |  |  | P07 | 11 | D/C
11 | 32Kp |  |  |  | P21 | 12 | nCS
12 | 32Km |  |  |  | P01 | 13 | SCLK
13 | P22 | U5.1 | HLT_CTL | NC (traced) | P20 | 14 | SDI
14 | VBAT_RF |  |  |  |  | 15 | VDDIO
15 | VBAT3V |  |  |  |  | 16 | VCI
16 | GND |  |  |  |  | 17 | VSS
17 | RST |  |  |  |  | 18 | VDDIO
18 | P23 | PWR_EN |  | free - drives Q3 (traced) |  | 19 | VPP
19 | VDCDC |  |  |  |  | 20 | VSH
20 | P24 | 接U4 |  | NC (traced) |  | 21 | PREVGH
 |  |  |  |  |  | 22 | VSL
21 | SWITCH |  |  |  |  | 23 | PREVGL
22 | P10 | U5.10 | RST | NC (traced) |  | 24 | VCOM
23 | VBAT1V
24 | P11 | U5.9 | BUSY | NC (traced)
25 | SWDIO |  |  |  | 在Flash的0x39000处，保存有GPIO的配置信息
26 | SWCLK
27 | P12 | - |  | NC (traced)
28 | P13 | - |  | NC (traced)
29 | 16Mp
30 | 16Mm
31 | VDCDC_RF
32 | P25 | LED_Green |  | free - unpopulated D1/R4 (traced)
33 | P26 | - |  | NC (traced)
34 | RFIOm
35 | RFIOp
36 | P27 | - |  | NC (traced)
37 | P28 | - |  | NC (traced)
38 | VDD
39 | P29 | LED_Blue |  | NC (traced)
40 | P20 | U5.14 | SDI | SNES LATCH (pad E09, traced)

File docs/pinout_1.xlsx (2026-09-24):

1 | P00 | SPI.CLK | SCLK | P22 | 1 | HLT_CTL
2 | P01 | U5.13 |  |  | 2 | GDR
3 | P02 | LED_Red |  |  | 3 | RESE
4 | P03 | SPI.CS |  |  | 4 | VGL
5 | P30 | - |  |  | 5 | VGH
6 | P04 | UART_TX |  |  | 6 | TSCL | 温控IIC接口
7 | P05 | SPI.SO | DC |  | 7 | TSDA
8 | P21 | U5.12 | CS |  | 8 | BS | 1:3线 0:4线
9 | P06 | SPI.SI | SDI | P11 | 9 | nBUSY
10 | P07 | U5.11 | RST | P10 | 10 | nRST
 |  |  |  | P07 | 11 | D/C
11 | 32Kp |  |  | P21 | 12 | nCS
12 | 32Km |  |  | P01 | 13 | SCLK
13 | P22 | U5.1 |  | P20 | 14 | SDI
14 | VBAT_RF |  |  |  | 15 | VDDIO
15 | VBAT3V |  |  |  | 16 | VCI
16 | GND |  |  |  | 17 | VSS
17 | RST |  |  |  | 18 | VDDIO
18 | P23 | PWR_EN |  |  | 19 | VPP
19 | VDCDC |  |  |  | 20 | VSH
20 | P24 | 接U4 |  |  | 21 | PREVGH
 |  |  |  |  | 22 | VSL
21 | SWITCH |  |  |  | 23 | PREVGL
22 | P10 | U5.10 |  |  | 24 | VCOM
23 | VBAT1V
24 | P11 | U5.9
25 | SWDIO |  |  | 在Flash的0x39000处，保存有GPIO的配置信息
26 | SWCLK
27 | P12 | -
28 | P13 | -
29 | 16Mp
30 | 16Mm
31 | VDCDC_RF
32 | P25 | LED_Green
33 | P26 | -
34 | RFIOm
35 | RFIOp
36 | P27 | -
37 | P28 | -
38 | VDD
39 | P29 | LED_Blue
40 | P20 | U5.14 | BUSY

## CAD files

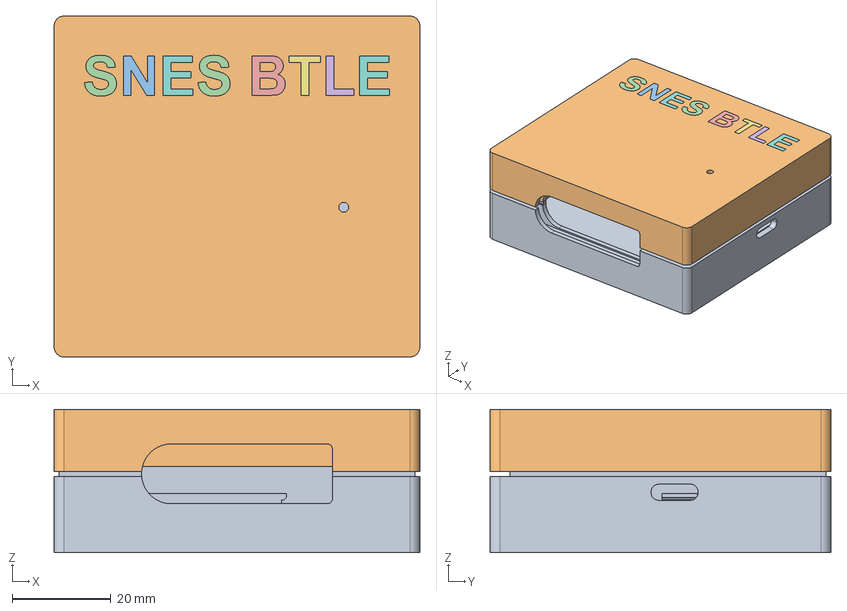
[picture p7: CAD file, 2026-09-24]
3D/SNES BLE.step
74.0 x 69.0 x 29.0 mm

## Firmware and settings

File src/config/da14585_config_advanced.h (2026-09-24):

/**
 ****************************************************************************************
 *
 * @file da14585_config_advanced.h
 *
 * @brief Advanced compile configuration file.
 *
 * Copyright (C) 2014-2024 Renesas Electronics Corporation and/or its affiliates.
 * All rights reserved. Confidential Information.
 *
 * This software ("Software") is supplied by Renesas Electronics Corporation and/or its
 * affiliates ("Renesas"). Renesas grants you a personal, non-exclusive, non-transferable,
 * revocable, non-sub-licensable right and license to use the Software, solely if used in
 * or together with Renesas products. You may make copies of this Software, provided this
 * copyright notice and disclaimer ("Notice") is included in all such copies. Renesas
 * reserves the right to change or discontinue the Software at any time without notice.
 *
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
 ****************************************************************************************
 */

#ifndef _DA14585_CONFIG_ADVANCED_H_
#define _DA14585_CONFIG_ADVANCED_H_

#include "da1458x_stack_config.h"

/****************************************************************************************************************/
/* Low Power clock selection.                                                                                   */
/*      -LP_CLK_XTAL32      External XTAL32K oscillator                                                         */
/*      -LP_CLK_RCX20       Internal RCX clock                                                                  */
/*      -LP_CLK_FROM_OTP    Use the selection in the corresponding field of OTP Header                          */
/****************************************************************************************************************/
#define CFG_LP_CLK              LP_CLK_XTAL32

/****************************************************************************************************************/
/* If defined the application uses a hardcoded value for XTAL16M trimming. Should be disabled for devices       */
/* where XTAL16M is calibrated and trim value is stored in OTP.                                                 */
/* Important note. The hardcoded value is the average value of the trimming values giving the optimal results   */
/* for DA14585 DK devices. May not be applicable in other designs                                               */
/****************************************************************************************************************/
#define CFG_USE_DEFAULT_XTAL16M_TRIM_VALUE_IF_NOT_CALIBRATED

/****************************************************************************************************************/
/* Periodic wakeup period to poll GTL iface. Time in msec.                                                      */
/****************************************************************************************************************/
#define CFG_MAX_SLEEP_DURATION_PERIODIC_WAKEUP_MS                  500  // 0.5s

/****************************************************************************************************************/
/* Periodic wakeup period if GTL iface is not enabled. Time in msec.                                            */
/****************************************************************************************************************/
#define CFG_MAX_SLEEP_DURATION_EXTERNAL_WAKEUP_MS              600000  // 600s

/****************************************************************************************************************/
/* Wakeup from external processor running host application.                                                     */
/****************************************************************************************************************/
#undef CFG_EXTERNAL_WAKEUP

/****************************************************************************************************************/
/* Wakeup external processor when a message is sent to GTL                                                      */
/****************************************************************************************************************/
#undef CFG_WAKEUP_EXT_PROCESSOR
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

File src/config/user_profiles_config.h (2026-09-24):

/**
 ****************************************************************************************
 *
 * @file user_profiles_config.h
 *
 * @brief Configuration file for the profiles used in the application.
 *
 * Copyright (C) 2015-2023 Renesas Electronics Corporation and/or its affiliates.
 * All rights reserved. Confidential Information.
 *
 ****************************************************************************************
 */

#ifndef _USER_PROFILES_CONFIG_H_
#define _USER_PROFILES_CONFIG_H_

/**
 ****************************************************************************************
 * @defgroup APP_CONFIG
 * @ingroup APP
 * @brief  Application configuration file
 *
 * This file contains the configuration of the profiles used by the application.
 *
 * @{
 ****************************************************************************************
 */

/*
 * DEFINITIONS
 ****************************************************************************************
 */

/***************************************************************************************/
/* Used BLE profiles (used by "rwprf_config.h").                                       */
/***************************************************************************************/

/// HID over GATT Profile - Device role (HOGPD)
#define CFG_PRF_HOGPD
#define CFG_PRF_BASS
/// Device Information Service: required by HOGP; exposes manufacturer, model, firmware version
#define CFG_PRF_DISS
/// SUOTA receiver (over-the-air update). Locked (SRV_PERM_DISABLE) unless the pad was powered
/// on with Start + Select held; then it needs an encrypted link (see user_app_init()).
#define CFG_PRF_SUOTAR

/// The SDK app_bass module is compiled but unused (user_batt_* in user_hid_hogpd.c replaces it,
/// the SDK one is CR2032-only). These only satisfy its build; there is no battery LED.
#define USE_BAT_LEVEL_ALERT             (0)
#define GPIO_BAT_LED_PORT               GPIO_PORT_0
#define GPIO_BAT_LED_PIN                GPIO_PIN_0
#define APP_BASS_POLL_INTERVAL          (6000)

/***************************************************************************************/
/* Profile application configuration section                                           */
/***************************************************************************************/

/*
 ****************************************************************************************
 * HOGPD application profile configuration
 ****************************************************************************************
 */

/// Number of HID service instances exposed by the device (1 = a single HID gamepad)
#define APP_HOGPD_HIDS_NB               (1)

/// Service features: Report protocol mode only (no boot protocol for gamepad)
#define APP_HOGPD_SVC_FEATURES          (HOGPD_CFG_PROTO_MODE)

/// Number of Report characteristics in the HID service (a single Report-protocol input report)
#define APP_HOGPD_REPORT_NB             (1)

/// Report characteristics configuration: Report #0 is an input report (notifiable)
#define APP_HOGPD_REPORT_CHAR_CFG       { HOGPD_CFG_REPORT_IN, 0, 0, 0, 0 }

/// Report IDs assigned to the reports (must match the Report Map)
#define APP_HOGPD_REPORT_IDS            { 1, 0, 0, 0, 0 }

/// bcdHID release of the gamepad (1.01)
#define APP_HOGPD_BCD_HID               (0x0101)

/// HID Information flags: normally connectable + remote wake capable
#define APP_HOGPD_HID_FLAGS             (HIDS_NORM_CONNECTABLE | HIDS_REMOTE_WAKE_CAPABLE)

/*
 ****************************************************************************************
 * DISS application profile configuration
 ****************************************************************************************
 */

#include "app_version.h"                // APP_VERSION, APP_VERSION_BCD

#define APP_DIS_FEATURES                (DIS_MANUFACTURER_NAME_CHAR_SUP | \
                                         DIS_MODEL_NB_STR_CHAR_SUP | \
                                         DIS_FIRM_REV_STR_CHAR_SUP | \
                                         DIS_PNP_ID_CHAR_SUP)

#define APP_DIS_MANUFACTURER_NAME       ("motionfxdesign")
#define APP_DIS_MANUFACTURER_NAME_LEN   (sizeof(APP_DIS_MANUFACTURER_NAME) - 1)

#define APP_DIS_MODEL_NB_STR            ("BT-SNES")
#define APP_DIS_MODEL_NB_STR_LEN        (sizeof(APP_DIS_MODEL_NB_STR) - 1)

#define APP_DIS_FIRM_REV_STR            APP_VERSION
#define APP_DIS_FIRM_REV_STR_LEN        (sizeof(APP_DIS_FIRM_REV_STR) - 1)
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

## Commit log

2026-09-24 BT-SNES: SNES controller to Bluetooth adapter (DA14585) - v0.5.4
    Firmware for a repurposed e-paper ESL board (Renesas DA14585) that turns
    an original SNES controller into a Bluetooth LE HID gamepad.
    - HID over GATT gamepad (12 buttons), SNES pad read on E09/E10/E12
    - Battery Service (VBAT, 2.2-2.8 V scale), Device Information Service
    - Deep sleep after 3 min idle (advertising or connected); B wakes it
    - Signed OTA updates (SUOTA + ECDSA P-256, ROM micro-ecc); OTA mode via
    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
    [pinout_0.xlsx, pinout_1.xlsx]
2026-09-24 v0.5.5: SSOT cleanup, production hardening, OTA-mode detection
    SSOT:
    - Version only in src/config/app_version.h (VERSION file removed).
    - selflash.c / ota_verify.c use the SDK's app_suotar.h header layout and
    app_bond_db.h bond-DB address instead of private copies.
    - HID report length, padding and mask derive from SNES_BUTTON_COUNT
    (compile-time checks for the count and snes_map[]).
    - Tool protocol constants in tools/suota_protocol.json, shared by
    suota.py (bundled into suota.exe) and tools/web.
    Production:
    - OTA mode idles out after 10 min (was: never) -> deep sleep; a transfer
    counts as activity.
    - L + R + Start + Select held 3 s reboots into OTA mode (no power cycle
    needed on b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
    [ota_verify.c, selflash.c, suota.py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]
2026-09-24 Docs: SNES_BLE_HID readme, hardware, 3D case, programming jig
    - Readme: adapter intro + repo link, Hardware section (prototype and
    assembled photos, power chain), 3D-printed case (render + STEP model
    in 3D/), SWD programming jig, updated project layout, web tester
    (live version, OTA-mode detection), OTA steps, troubleshooting rows,
    P1_4/P1_5 are the SWD pins, battery scale wording, fixed pad table.
    - user_periph_setup.h: pin comment - P1_4/P1_5 = SWCLK/SWDIO.
    - images: descriptive names; old board photo replaced by programming.png.
    [SNES BLE.step]
